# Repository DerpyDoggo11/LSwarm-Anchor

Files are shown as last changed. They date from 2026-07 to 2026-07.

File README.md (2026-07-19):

# LSwarm Anchor
A UWB Anchor made for the LSwarm micro drones

## 3D Preview
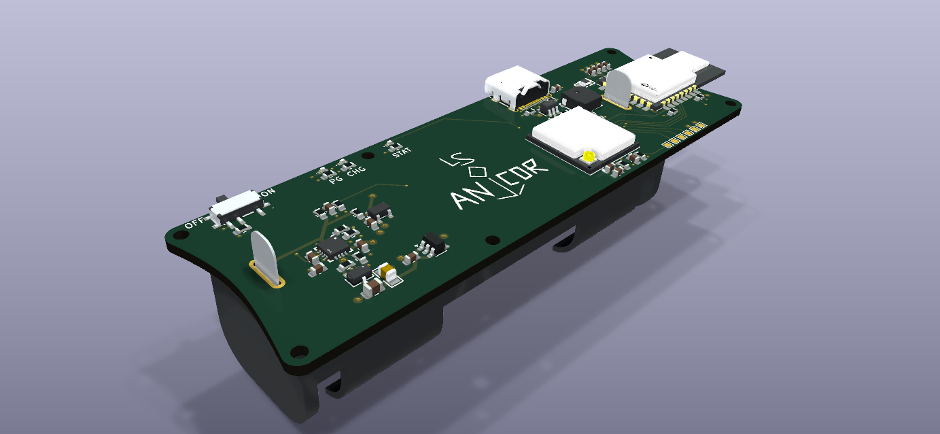
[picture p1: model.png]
3D PCB


## Wiring
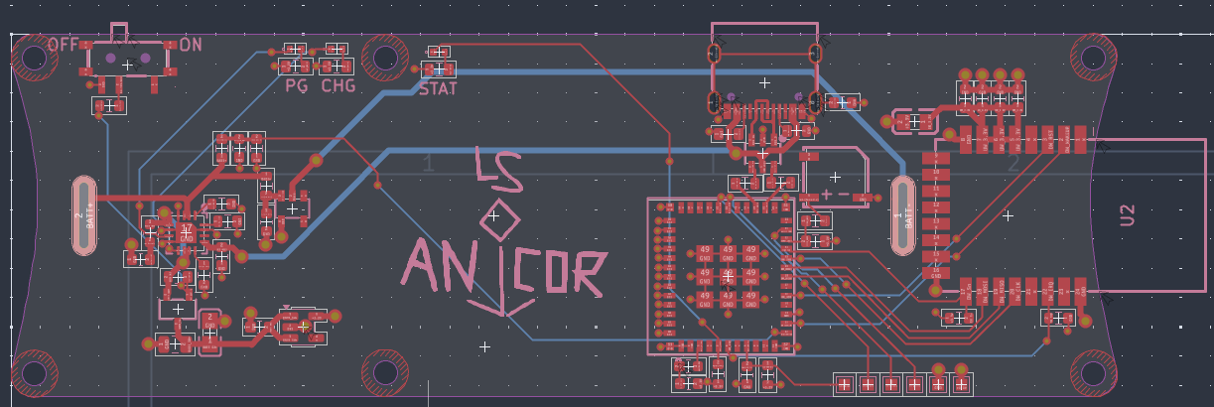
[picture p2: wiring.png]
PCB


## Schematic
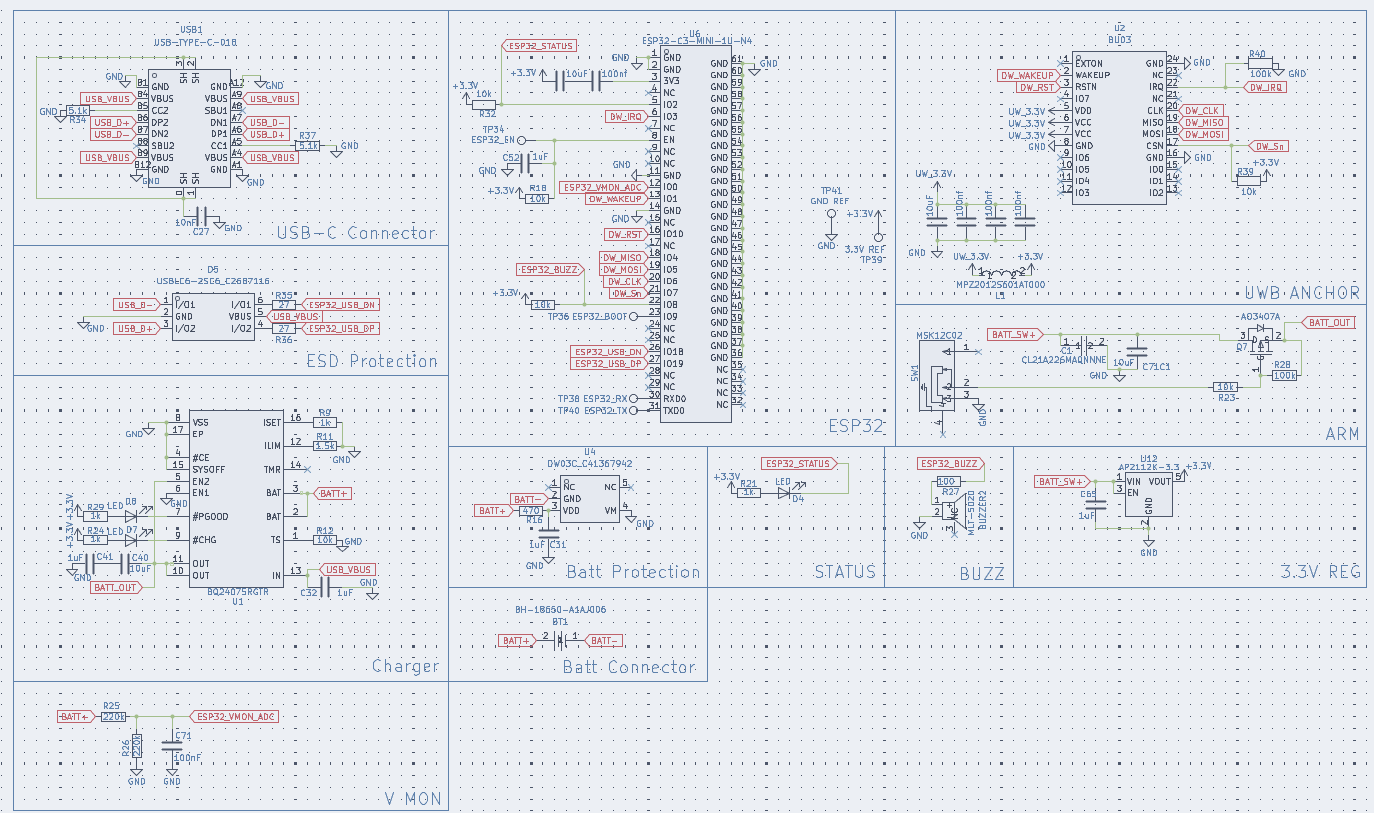
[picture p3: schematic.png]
Schematic


### Download ./latestProduction to begin fabricating the PCB

## Introduction
In an effort to make a cheaper alternative for micro drones, specifically for volumetric (3D) light displays, I designed drones that use an ultra-wide-band (UWB) module instead of an expensive gps to communicate with ground stations with UWB modules often called anchors. With three of these modules placed in a triangular formation, you can estimate the drone's specific position in 2D space. With four or more of these modules, you can precisely track the drone's position in a full 3D space. I recommend around 5 modules for more precision (also LCSC tends to offer pcbs in terms of 5 which makes this almost just as cheap), but four modules will work as well. 

I have not physically tested this device yet, but typically UWB modules can have a range of up to 100 meters or around 300 feet, which is more than enough for many applications. Also, UWB frequenceis can work through walls, but it may be less accurate or cause desyncing with the drone. 

Note: These anchors do not actively run the computations to position the drones, you must also have a dedicated ground station with wifi such as a Raspbbery PI Zero 2 W for computing.

## Bill of Materials (for 5 anchors)

| Quantity | Components | Price | Link |
|--- |---|---| -----|
| 5  | 18650 Batteries | ~$33.93 (with shipping) | [here](https://liionwholesale.com/products/molicel-npe-inr-18650-m35a-10a-3500mah-flat-top-18650-battery-authorized-distributor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)
| 5 | 2.4G Wifi Antenna | ~$1.39 | select 5cm FPC-IPX4 cable from [here](https://www.aliexpress.us/item/3256802833801038.html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)
| 5  | LS Anchor PCBs | ~$10 (with shipping, cost can vary widely however) | Download repo, extract fabrication files, and fabricate through JLCPCB (complete instructions for this may come soon)
| 5  | Electrical Components for each PCB | ~$88.67 (this is on the high end, cost can vary widely) | See production BOM for a full list, the PCB fabrication files automatically include these components as well.
Total: $133.99

## Tools / Other parts:
- Hot-air reflow station or SMD hot plate
- Soldering iron + solder
- Solder paste for SMD components
- Tweezers for SMD components

For drone light displays, you'll also need the drones and a ground station.

## Assembly:
1. Apply solder paste to all smd components directly or through a stencil
2. Heat up components with a hot plate or hot-air gun
3. Solder on the battery connector and connect the battery
4. Plug in USB-C port and upload software

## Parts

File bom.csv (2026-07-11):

Quantity | Component | Price | Link | Notes
5 | 18650 Battery | $33.93 | https://liionwholesale.com/products/molicel-npe-inr-18650-m35a-10a-3500mah-flat-top-18650-battery-authorized-distributor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
5 | 2.4G WIfi Antenna | $1.39 | https://www.aliexpress.us/item/3256802833801038.html?curPageLogUid=rLnZuf4b98Bi | select 5cm FPC-IPX4 cable
5 | LS Anchor PCBs | $10.00 | Download repo, extract fabrication files, and fabricate through JLCPCB
5 | Electrical components for each PCB | $88.67 | See production BOM for a full list, the PCB fabrication files automatically include these components as well.
Total: | $133.99

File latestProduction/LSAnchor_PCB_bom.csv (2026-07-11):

Designator | Footprint | Quantity | Value | LCSC Part #
BT1 | BAT-TH_BH-18650-A1AJ006 | 1 | BH-18650-A1AJ006 | C5290175
BUZZER2 | BUZ-SMD_L5.0-W5.5-P4.60 | 1 | MLT-5020 | C94598
C1 | C0805 | 1 | CL21A226MAQNNNE | C45783
C27 | 0603 | 1 | 10nF
C31, C32, C41, C52, C65 | 0603 | 5 | 1uF
C40, C55, C62 | 0603 | 3 | 10uF
C56, C58, C59, C61, C71 | 0603 | 5 | 100nf
C71C1 | 0805 | 1 | 10uF
D5 | SOT-23-6_L2.9-W1.6-P0.95-LS2.8-BL | 1 | USBLC6-2SC6_C2687116 | C2687116
L1 | L0805 | 1 | MPZ2012S601AT000 | C21519
LED4, LED5, LED6 | LED-SMD_L1.6-W0.8-R-RD | 3 | KT-0603R | C2286
Q7 | SOT-23-3_L2.9-W1.6-P1.90-LS2.8-BR | 1 | AO3407A | C15155
R11 | 0603 | 1 | 1.5k ohm
R12, R18, R23, R32, R33, R39 | 0603 | 6 | 10k ohm
R16 | 0603 | 1 | 470 ohm
R21, R24, R29, R9 | 0603 | 4 | 1k ohm
R25, R26 | 0603 | 2 | 220k ohm
R27 | 0603 | 1 | 100 ohm
R28, R40 | 0603 | 2 | 100k ohm
R34, R37 | 0603 | 2 | 5.1k ohm
R35, R36 | 0603 | 2 | 27 ohm
SW1 | SW-TH_MSK12C02 | 1 | MSK12C02 | C431540
TP34 | TestPoint_Pad_1.0x1.0mm | 1 | ESP32_EN
TP36 | TestPoint_Pad_1.0x1.0mm | 1 | ESP32_BOOT
TP38 | TestPoint_Pad_1.0x1.0mm | 1 | ESP32_RX
TP39 | TestPoint_Pad_1.0x1.0mm | 1 | 3.3V REF
TP40 | TestPoint_Pad_1.0x1.0mm | 1 | ESP32_TX
TP41 | TestPoint_Pad_1.0x1.0mm | 1 | GND REF
U1 | QFN-16_L3.0-W3.0-P0.50-TL-EP1.7 | 1 | BQ24075RGTR | C15464
U12 | SOT-23-5 | 1 | AP2112K-3.3
U2 | WIRELM-SMD_BU03 | 1 | BU03 | C42419011
U4 | SOT-23-5_L2.9-W1.6-P0.95-LS2.9-BL | 1 | DW03C_C41367942 | C41367942
U6 | WIFIM-SMD_61P-L13.2-W12.5-P0.80 | 1 | ESP32-C3-MINI-1U-N4 | C2911374
USB1 | USB-C_SMD-TYPE-C-31-M-12 | 1 | USB-TYPE-C-018 | C2927038

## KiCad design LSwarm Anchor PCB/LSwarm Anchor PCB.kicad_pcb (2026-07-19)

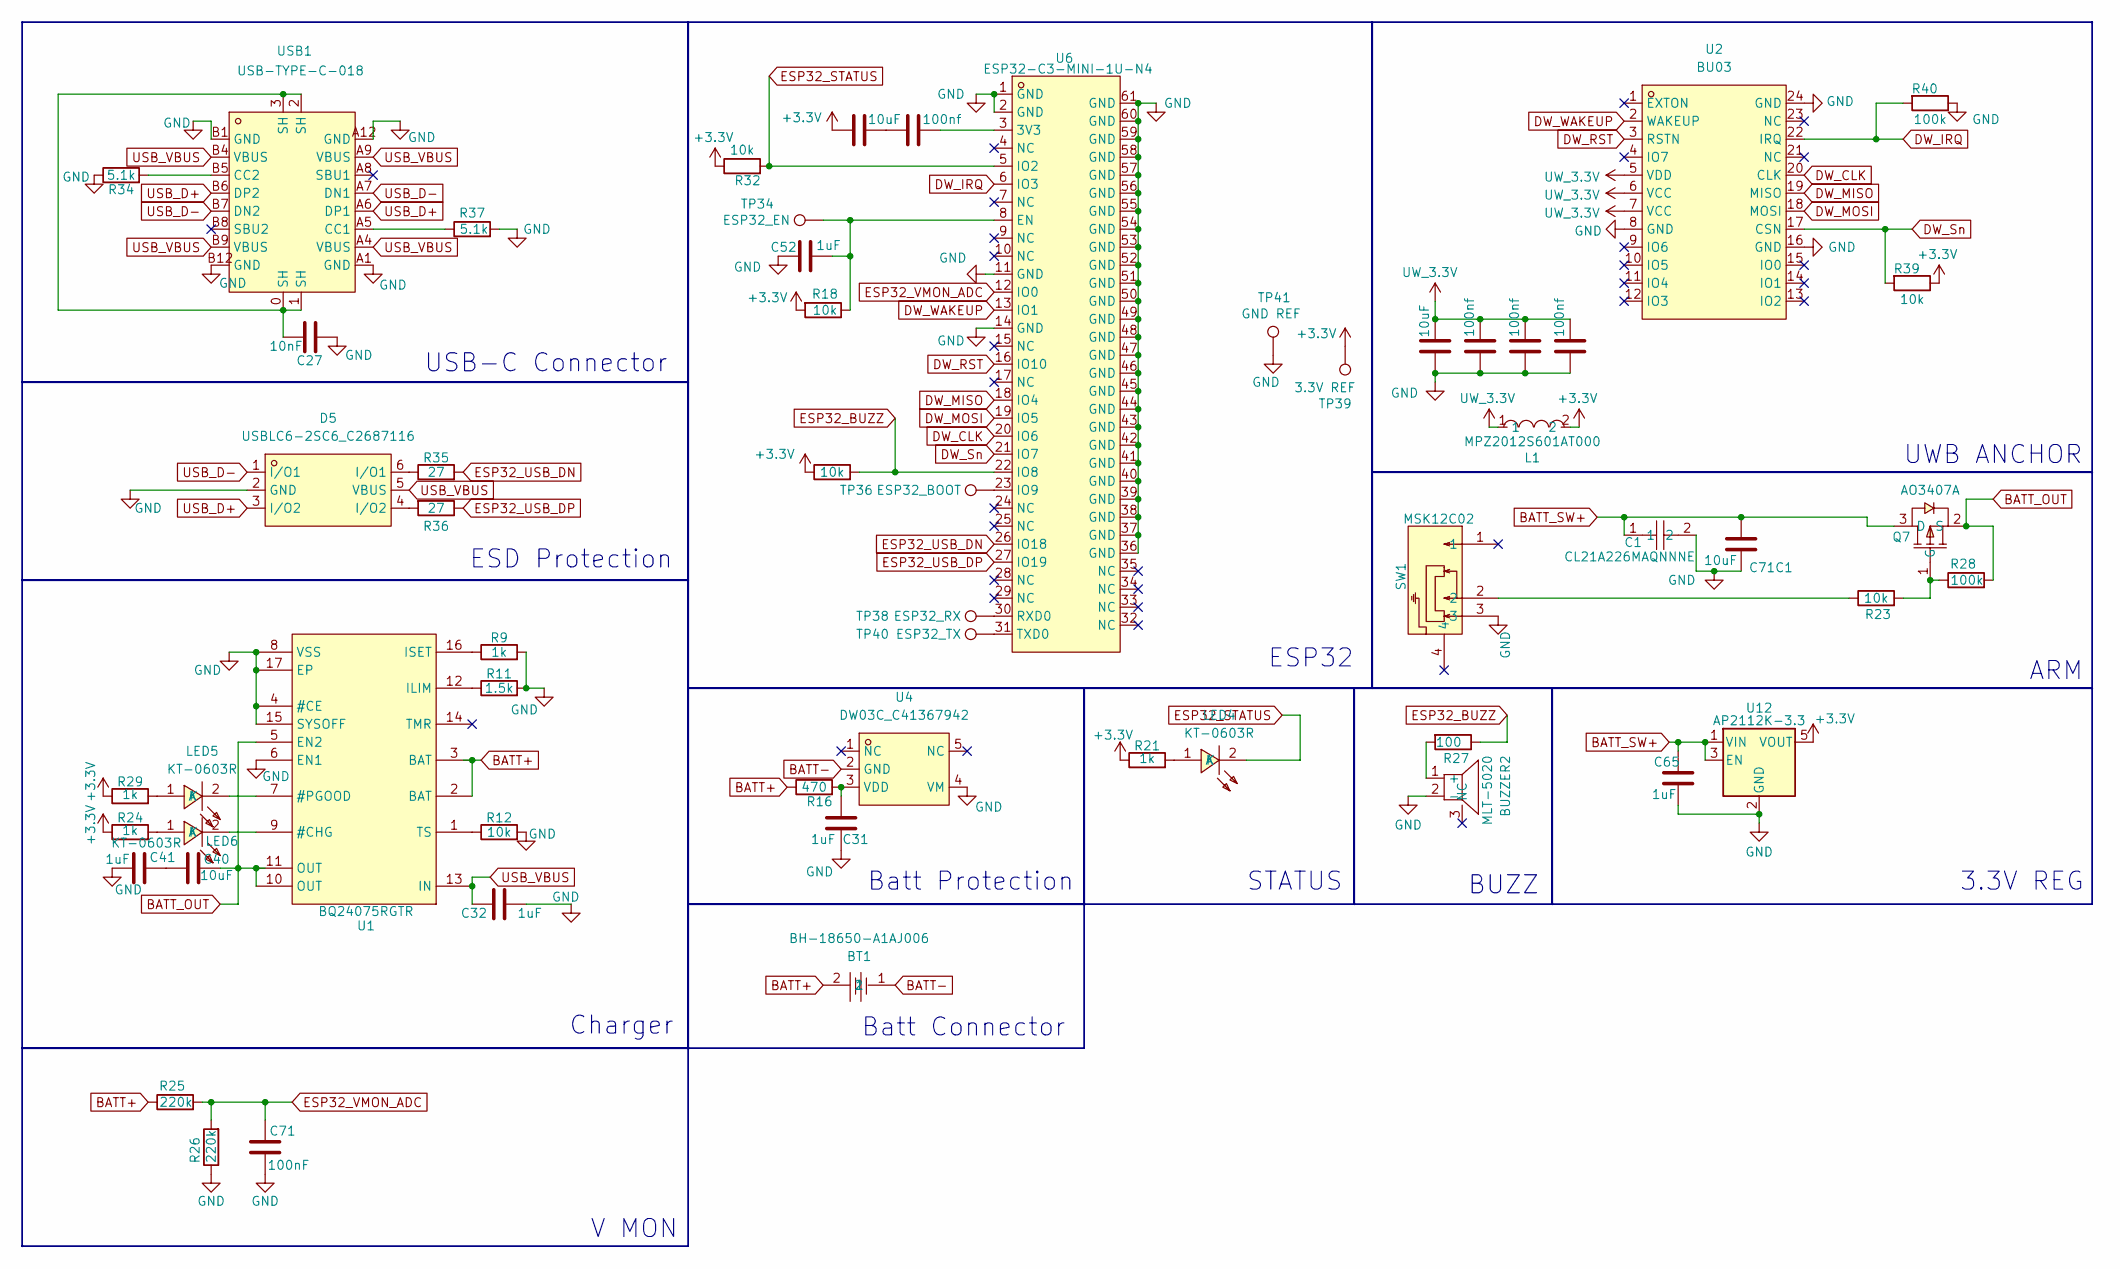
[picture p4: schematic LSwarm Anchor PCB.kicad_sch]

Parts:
BT1: BH-18650-A1AJ006; BAT-TH_BH-18650-A1AJ006; MPN BH-18650-A1AJ006; LCSC Part C5290175
BUZZER2: MLT-5020; BUZ-SMD_L5.0-W5.5-P4.60; MPN MLT-5020; LCSC Part C94598
C1: CL21A226MAQNNNE; C0805; MPN CL21A226MAQNNNE; LCSC Part C45783
C27: 10nF; C_0603_1608Metric
C31, C32, C41, C52, C65: 1uF; C_0603_1608Metric
C40, C55, C62: 10uF; C_0603_1608Metric
C56, C58, C59, C61: 100nf; C_0603_1608Metric
C71: 100nF; C_0603_1608Metric
C71C1: 10uF; C_0805_2012Metric
D5: USBLC6-2SC6_C2687116; SOT-23-6_L2.9-W1.6-P0.95-LS2.8-BL; MPN USBLC6-2SC6; LCSC Part C2687116
L1: MPZ2012S601AT000; L0805; MPN MPZ2012S601AT000; LCSC Part C21519
LED4, LED5, LED6: KT-0603R; LED-SMD_L1.6-W0.8-R-RD; MPN KT-0603R; LCSC Part C2286
Q7: AO3407A; SOT-23-3_L2.9-W1.6-P1.90-LS2.8-BR; MPN AO3407A; LCSC Part C15155
R9, R21, R24, R29: 1k; R_0603_1608Metric
R11: 1.5k; R_0603_1608Metric
R12, R18, R23, R32, R33, R39: 10k; R_0603_1608Metric
R16: 470; R_0603_1608Metric
R25, R26: 220k; R_0603_1608Metric
R27: 100; R_0603_1608Metric
R28, R40: 100k; R_0603_1608Metric
R34, R37: 5.1k; R_0603_1608Metric
R35, R36: 27; R_0603_1608Metric
SW1: MSK12C02; SW-TH_MSK12C02; MPN MSK12C02; LCSC Part C431540
TP34: ESP32_EN; TestPoint_Pad_1.0x1.0mm
TP36: ESP32_BOOT; TestPoint_Pad_1.0x1.0mm
TP38: ESP32_RX; TestPoint_Pad_1.0x1.0mm
TP39: 3.3V REF; TestPoint_Pad_1.0x1.0mm
TP40: ESP32_TX; TestPoint_Pad_1.0x1.0mm
TP41: GND REF; TestPoint_Pad_1.0x1.0mm
U1: BQ24075RGTR; QFN-16_L3.0-W3.0-P0.50-TL-EP1.7; MPN BQ24075RGTR; LCSC Part C15464
U2: BU03; WIRELM-SMD_BU03; MPN BU03; LCSC Part C42419011
U4: DW03C_C41367942; SOT-23-5_L2.9-W1.6-P0.95-LS2.9-BL; MPN DW03C; LCSC Part C41367942
U6: ESP32-C3-MINI-1U-N4; WIFIM-SMD_61P-L13.2-W12.5-P0.80; MPN ESP32-C3-MINI-1U-N4; LCSC Part C2911374
U12: AP2112K-3.3; SOT-23-5
USB1: USB-TYPE-C-018; USB-C_SMD-TYPE-C-31-M-12; MPN USB-TYPE-C-018; LCSC Part C2927038

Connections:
+3.3V: C55.2, L1.2, R18.2, R21.1, R24.1, R29.1, R32.1, R33.1, R39.1, TP39.1 (1_1), U12.5 (VOUT)
BATT+: BT1.2, R16.1, R25.1, U1.2 (BAT), U1.3 (BAT)
BATT-: BT1.1, U4.2 (GND)
BATT_OUT: C40.1, Q7.2 (S), R28.2, U1.5 (EN2), U1.10 (OUT), U1.11 (OUT)
BATT_SW+: C1.1, C65.2, C71C1.2, Q7.3 (D), U12.1 (VIN), U12.3 (EN)
DW_CLK: U2.20 (CLK), U6.20 (IO6)
DW_IRQ: R40.2, U2.22 (IRQ), U6.6 (IO3)
DW_MISO: U2.19 (MISO), U6.18 (IO4)
DW_MOSI: U2.18 (MOSI), U6.19 (IO5)
DW_RST: U2.3 (RSTN), U6.16 (IO10)
DW_Sn: R39.2, U2.17 (CSN), U6.21 (IO7)
DW_WAKEUP: U2.2 (WAKEUP), U6.13 (IO1)
ESP32_BUZZ: R27.1, R33.2, U6.22 (IO8)
ESP32_STATUS: LED4.2 (K), R32.2, U6.5 (IO2)
ESP32_USB_DN: R35.2, U6.26 (IO18)
ESP32_USB_DP: R36.1, U6.27 (IO19)
ESP32_VMON_ADC: C71.2, R25.2, R26.2, U6.12 (IO0)
GND: BUZZER2.2 (-), C1.2, C27.1, C31.2, C32.1, C41.1, C52.1, C58.2, C59.2, C61.2, C62.2, C65.1, C71.1, C71C1.1, D5.2 (GND), R9.2, R11.2, R12.2, R26.1, R34.1, R37.2, R40.1, SW1.3, TP41.1 (1_1), U1.4 (#CE), U1.6 (EN1), U1.8 (VSS), U1.15 (SYSOFF), U1.17 (EP), U2.8 (GND), U2.16 (GND), U2.24 (GND), U4.4 (VM), U6.1 (GND), U6.2 (GND), U6.11 (GND), U6.14 (GND), U6.36 (GND), U6.37 (GND), U6.38 (GND), U6.39 (GND), U6.40 (GND), U6.41 (GND), U6.42 (GND), U6.43 (GND), U6.44 (GND), U6.45 (GND), U6.46 (GND), U6.47 (GND), U6.48 (GND), U6.49 (GND), U6.50 (GND), U6.51 (GND), U6.52 (GND), U6.53 (GND), U6.54 (GND), U6.55 (GND), U6.56 (GND), U6.57 (GND), U6.58 (GND), U6.59 (GND), U6.60 (GND), U6.61 (GND), U12.2 (GND), USB1.A1 (GND), USB1.A12 (GND), USB1.B1 (GND), USB1.B12 (GND)
unnamed: BUZZER2.1 (+), R27.2
unnamed: C27.2, USB1.0 (SH), USB1.1 (SH), USB1.2 (SH), USB1.3 (SH)
unnamed: C40.2, C41.2
unnamed: C55.1, C56.2
unnamed: D5.6 (I/O1), R35.1
unnamed: D5.4 (I/O2), R36.2
unnamed: LED4.1 (A), R21.2
unnamed: LED5.1 (A), R29.2
unnamed: LED5.2 (K), U1.7 (#PGOOD)
unnamed: LED6.1 (A), R24.2
unnamed: LED6.2 (K), U1.9 (#CHG)
unnamed: Q7.1 (G), R23.2, R28.1
unnamed: R23.1, SW1.2
unnamed: R11.1, U1.12 (ILIM)
unnamed: R9.1, U1.16 (ISET)
unnamed: R12.1, U1.1 (TS)
unnamed: C31.1, R16.2, U4.3 (VDD)
unnamed: C56.1, U6.3 (3V3)
unnamed: C52.2, R18.1, TP34.1 (1_1), U6.8 (EN)
unnamed: TP36.1 (1_1), U6.23 (IO9)
unnamed: TP38.1 (1_1), U6.30 (RXD0)
unnamed: TP40.1 (1_1), U6.31 (TXD0)
unnamed: R37.1, USB1.A5 (CC1)
unnamed: R34.2, USB1.B5 (CC2)
USB_D+: D5.3 (I/O2), USB1.A6 (DP1), USB1.B6 (DP2)
USB_D-: D5.1 (I/O1), USB1.A7 (DN1), USB1.B7 (DN2)
USB_VBUS: C32.2, D5.5 (VBUS), U1.13 (IN), USB1.A4 (VBUS), USB1.A9 (VBUS), USB1.B4 (VBUS), USB1.B9 (VBUS)
UW_3.3V: C58.1, C59.1, C61.1, C62.1, L1.1, U2.5 (VDD), U2.6 (VCC), U2.7 (VCC)

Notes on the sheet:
USB-C Connector
Batt Connector
BUZZ
V MON
STATUS
UWB ANCHOR
ESP32
3.3V REG
ARM
Batt Protection
Charger
ESD Protection

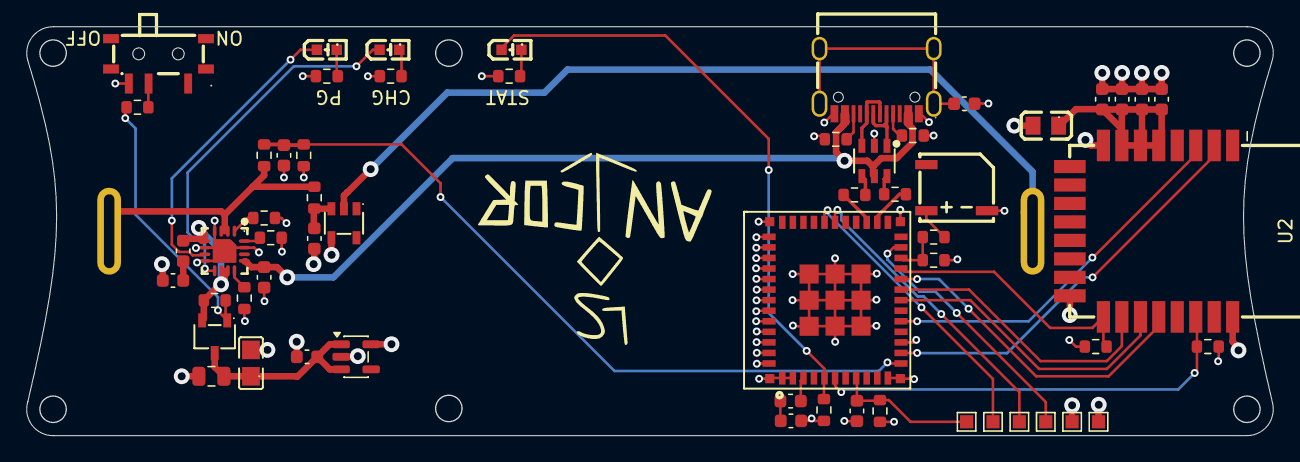
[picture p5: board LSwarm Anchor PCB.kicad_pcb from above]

Board: 4 copper layers, 94.5 x 31.0 mm, 58 parts (1 on the bottom side), 46 nets.

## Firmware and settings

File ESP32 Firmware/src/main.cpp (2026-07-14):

#include <Arduino.h>
#include "pins.h"
#include "uwb.h"
#include "hmi.h"

enum class Role : uint8_t { Anchor, Tag };
static Role g_role   = Role::Anchor;
static uint16_t g_addr   = 0x0001;
static float g_vbat   = 0.0f;

static void printStatus() {
    Serial.printf("role : %s\n", g_role == Role::Anchor ? "anchor" : "tag");
    Serial.printf("addr : 0x%04X\n", g_addr);
    Serial.printf("uwb : %s (devid 0x%08X)\n", Uwb::ok() ? "ok" : "NOT DETECTED", (unsigned int)Uwb::deviceId());
    Serial.printf("battery: %.2f V (%u%%)\n", g_vbat, Power::batteryPercent());
    Serial.printf("heap : %u bytes free\n", (unsigned)ESP.getFreeHeap());
}

static void handleCommand(char* cmd) {
    if (!strcmp(cmd, "help")) {
        Serial.println("help | id | stat | reset | batt | beep |");
        Serial.println("led on|off | role anchor|tag | mac <n>");
    } else if (!strcmp(cmd, "id")) {
        Serial.printf("devid 0x%08X\n", (unsigned int)Uwb::deviceId());
    } else if (!strcmp(cmd, "stat")) {
        printStatus();
    } else if (!strcmp(cmd, "reset")) {
        bool ok = Uwb::begin();
        Serial.printf("uwb reset -> %s\n", ok ? "ok" : "FAIL");
    } else if (!strcmp(cmd, "batt")) {
        Serial.printf("%.3f V  (%u%%)\n", Power::batteryVolts(),
                      Power::batteryPercent());
    } else if (!strcmp(cmd, "beep")) {
        Hmi::beep(120);
    } else if (!strcmp(cmd, "led on"))  { 
        Hmi::led(true); 
    } else if (!strcmp(cmd, "led off")) { 
        Hmi::led(false); 
    } else if (!strcmp(cmd, "role anchor")) {
        g_role = Role::Anchor; Serial.println("role = anchor");
    } else if (!strcmp(cmd, "role tag")) {
        g_role = Role::Tag;    Serial.println("role = tag");
    } else if (!strncmp(cmd, "mac ", 4)) {
        g_addr = (uint16_t)strtol(cmd + 4, nullptr, 0);
        Serial.printf("addr = 0x%04X\n", g_addr);
    } else if (cmd[0]) {
        Serial.println("? try 'help'");
    }
}

void setup() {
    Serial.begin(115200);

    Hmi::begin();
    Power::begin();

    while (!Serial && millis() - t0 < 2000) { delay(10); }

    bool ok = Uwb::begin();
    g_vbat  = Power::batteryVolts();

    printStatus();

    Hmi::beep(ok ? 60 : 300); 
}

void loop() {
    static char    line[64];
    static uint8_t n = 0;
    while (Serial.available()) {
        char c = (char)Serial.read();
        if (c == '\n' || c == '\r') {
            if (n) { line[n] = '\0'; handleCommand(line); n = 0; }
        } else if (n < sizeof(line) - 1) {
            line[n++] = c;
        }
    }


    static uint32_t tHk = 0;
    if (millis() - tHk >= 500) {
        tHk = millis();
        g_vbat = Power::batteryVolts();

        if (g_vbat < VBAT_WARN)   Hmi::blink(125);
        else if (!Uwb::ok())      Hmi::blink(500);
        else                      Hmi::led(true);

        static bool warned = false;
        if (g_vbat < VBAT_CRITICAL && !warned) {
            warned = true;
            Serial.printf("!! battery critical: %.2f V\n", g_vbat);
            Hmi::beep(400);
        } else if (g_vbat > VBAT_WARN) {
            warned = false;
        }
    }
}

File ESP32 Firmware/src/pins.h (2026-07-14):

#pragma once
#include <Arduino.h>


static constexpr int PIN_DW_WAKEUP = 1;
static constexpr int PIN_DW_IRQ    = 3;
static constexpr int PIN_DW_MISO   = 4;
static constexpr int PIN_DW_MOSI   = 5;
static constexpr int PIN_DW_CLK    = 6;
static constexpr int PIN_DW_CS     = 7;
static constexpr int PIN_DW_RST    = 10;

// HMI
static constexpr int PIN_STATUS_LED = 2; 
static constexpr int PIN_BUZZER = 21;

#define STATUS_LED_ACTIVE_LOW 1

// Power
static constexpr int   PIN_VMON_ADC = 0;
static constexpr float VBAT_DIVIDER = 2.0f;

static constexpr float VBAT_FULL     = 4.10f;
static constexpr float VBAT_WARN     = 3.40f;
static constexpr float VBAT_CRITICAL = 3.10f;
